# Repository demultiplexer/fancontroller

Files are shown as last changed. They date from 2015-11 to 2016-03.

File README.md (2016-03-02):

# Open source programmable fan controller

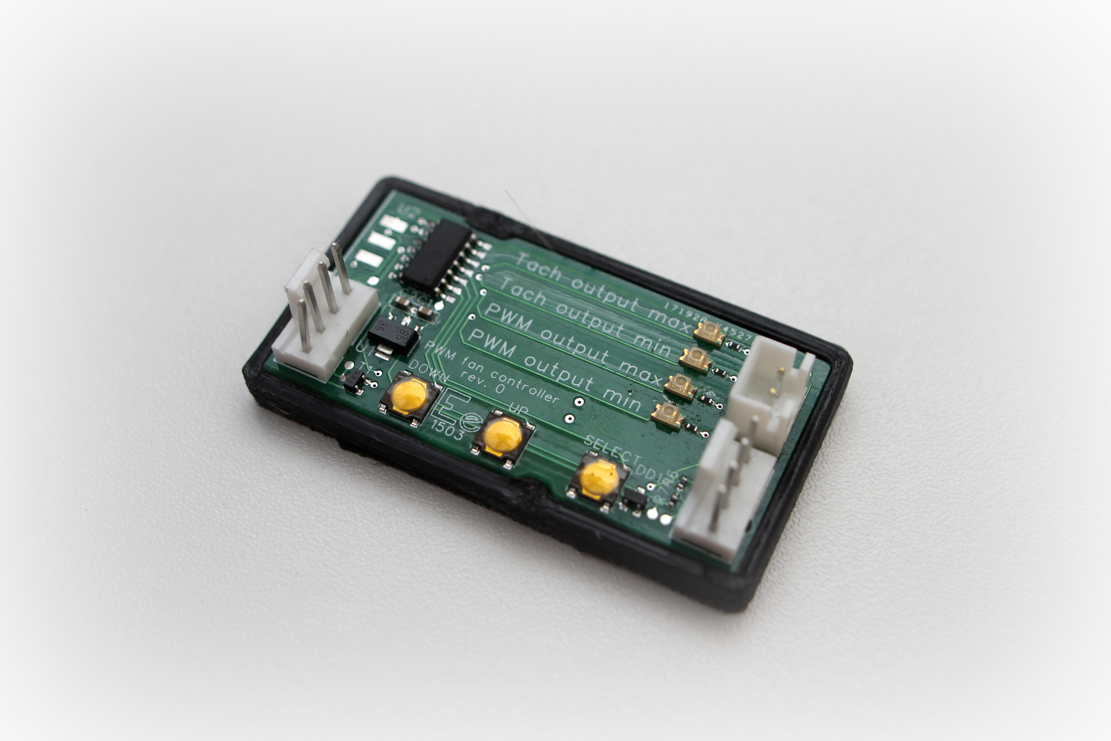
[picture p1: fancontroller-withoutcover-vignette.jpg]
Fan controller PCB and bottom printed enclosure shell (top shell removed)


This is an open source (commons) hardware project to create a fully programmable computer fan controller. The function of this board is to allow the user to both modify the PWM signal from the motherboard ("how fast the motherboard tells the fan to go") as well as the tachometer signal from the fan ("how fast the fan says it's spinning").

One application of this device is in server equipment that require fans to be present and spinning at a certain speed. These fans are often noisy and it helps to replace them with slower-spinning, quieter alternatives. However, motherboard firmware often rejects these fans. With this fan controller, the fan can pretend it's rotating faster than it really is.

This fan controller is completely open hardware and I highly encourage forking. Attribution is not required but I would really like it if you do mention me. I sell these boards including enclosure and wiring on my Tindie shop: https://www.tindie.com/stores/mux/

# Usage

The 4-pin fan connector on the left (marked "INPUT") should be connected to the motherboard using a straight 4-pin jumper cable. The 4-pin fan connector on the right should be connected to the fan. By default, the board does not interfere in the signals between motherboard and fan; it will just relay them as if it does not exist. 

By pressing the 'SELECT' (rightmost) button, you can cycle through the 4 settings: Tach min/max and PWM min/max. The corresponding LED will light up.

By pressing "UP" or "DOWN", the selected setting will be modified positively and negatively, respectively. 

Increasing or decreasing the "Tach output min" increases and decreases the minimum RPM signal that the board will send to the motherboard in steps of 500 rpm (steps of 1000 rpm above 5000 rpm). This way, the motherboard will 'think' the fan turns quicker than it actually does. The "Tach output max" signal works the same, but with respect to the upper limit of RPM.

Modifying the "PWM output min" and "PWM output max" settings changes how the fan responds to motherboard PWM signals. For instance, if both these settings are at 0, the fan controller will always output 0% PWM irrespective of the motherboard signal. Similarly, if the 'min' setting is at 50% and the 'max' setting is at 100%, the fan controller will instruct the fan to rotate at 50% even when the motherboard says it should rotate slower.

# How to build this

First of all, you can [buy it from me](https://www.tindie.com/stores/mux/). Barring that, you will need:

 - The PCB. You can order this at many PCB manufacturers like Itead studio, Seeed studio, Elecrow, PCBCART, Ledsee, Olimex, Eurocircuits. I have conveniently included a .zip file with all the gerber files in the required format for most manufacturers. Just go to their PCB prototyping service and upload [this file](/Gerber files/Orderable file format/fancontroller.zip).
 - The parts. I order my parts at nl.farnell.com, the Dutch branch of Element 14. The part list uses Farnell part numbers. If you have a Farnell account, go to your shopping cart and go to the link 'Quick Paste'. Then paste the text inside [this file](/schematics and PCB layout/BOM-element14.txt) into the entry box and you are done.
 - The enclosure. This can be printed using the .stl files provided in [this folder](/enclosure/). This folder also has some examples of how the enclosure should look in your 3D printing software. *PLEASE READ THE INSTRUCTIONS IN 'enclosure/instructions.txt'*
 - A straight 4-pin fan cable. You can either make this yourself using [this connector housing](http://nl.farnell.com/wurth-elektronik/61900411621/housing-2-54mm-4way/dp/1841379), [these contacts](http://nl.farnell.com/wurth-elektronik/61900113722dec/contact-2-54mm-crimp-awg28-22/dp/1841425), some wire and suitable crimpling pliers, or you can try to find ready-made cables on e.g. eBay. I do not currently have any recommendations for ready-made cables.
 - An AVRISP mkII or other AVR programmer witht 6-pin programming header
 - Either Atmel Studio 6.2+ or avrdude. The project is Atmel Studio-based, but you can just flash [the .hex file](/firmware-v2/fancontroller-v2/fancontroller-v2/Debug)
 
 The PCB uses pretty coarse parts, it should be solderable by anybody with a smattering of soldering experience. Don't be afraid of the SOT-323 parts on the board, nor the 0402 resistors; anybody can solder those if you just try :) For the best soldering results, I highly recommend using solder paste and oven reflow. The buttons ARE reflow compatible. I recommend the website [smtstencil.co.uk](http://smtstencil.co.uk/) for all your stencil needs. The gerber files for standard stencils are inside the gerber folder.
 
 After you produced the board and enclosure, you need to program it. The board has a side-mounted footprint for a standard AVRISP mkII programming header, with pin 1 on the REVERSE SIDE of the board. The enclosure does not support this header, so after you are done programming you need to desolder it to fit it into the enclosure.
 
 # Firmware hacking
 
I highly recommend watching the in-depth technical explanation videos on my Youtube channel: https://youtube.com/PowerElectronicsBlog

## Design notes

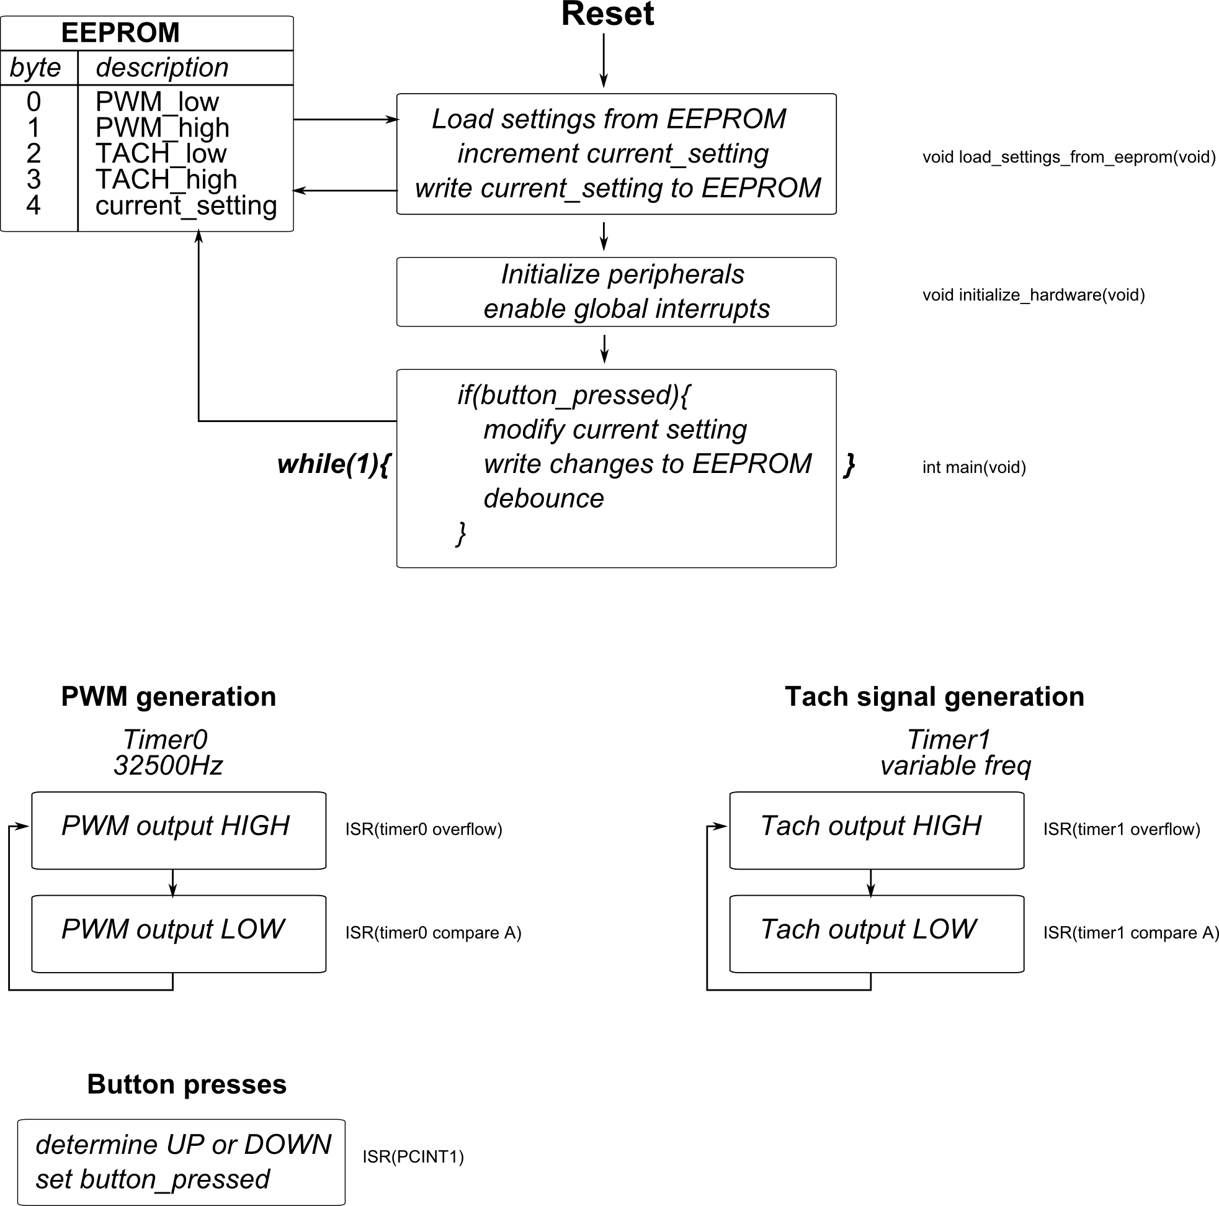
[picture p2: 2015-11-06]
firmware-flowchart-overview.png

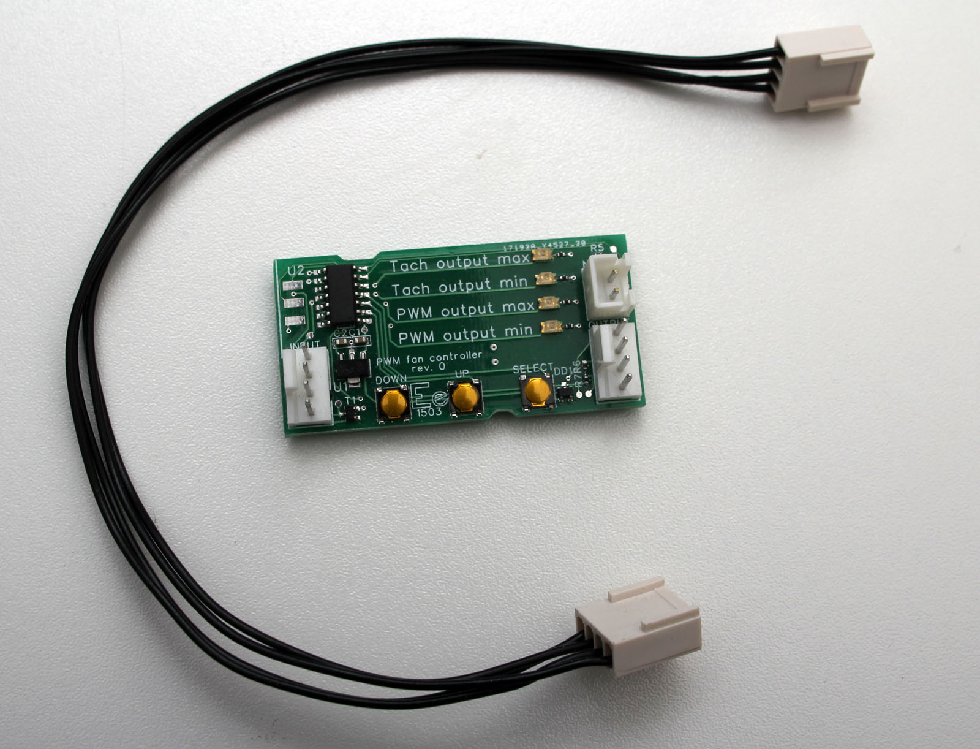
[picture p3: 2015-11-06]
overview-set.jpg

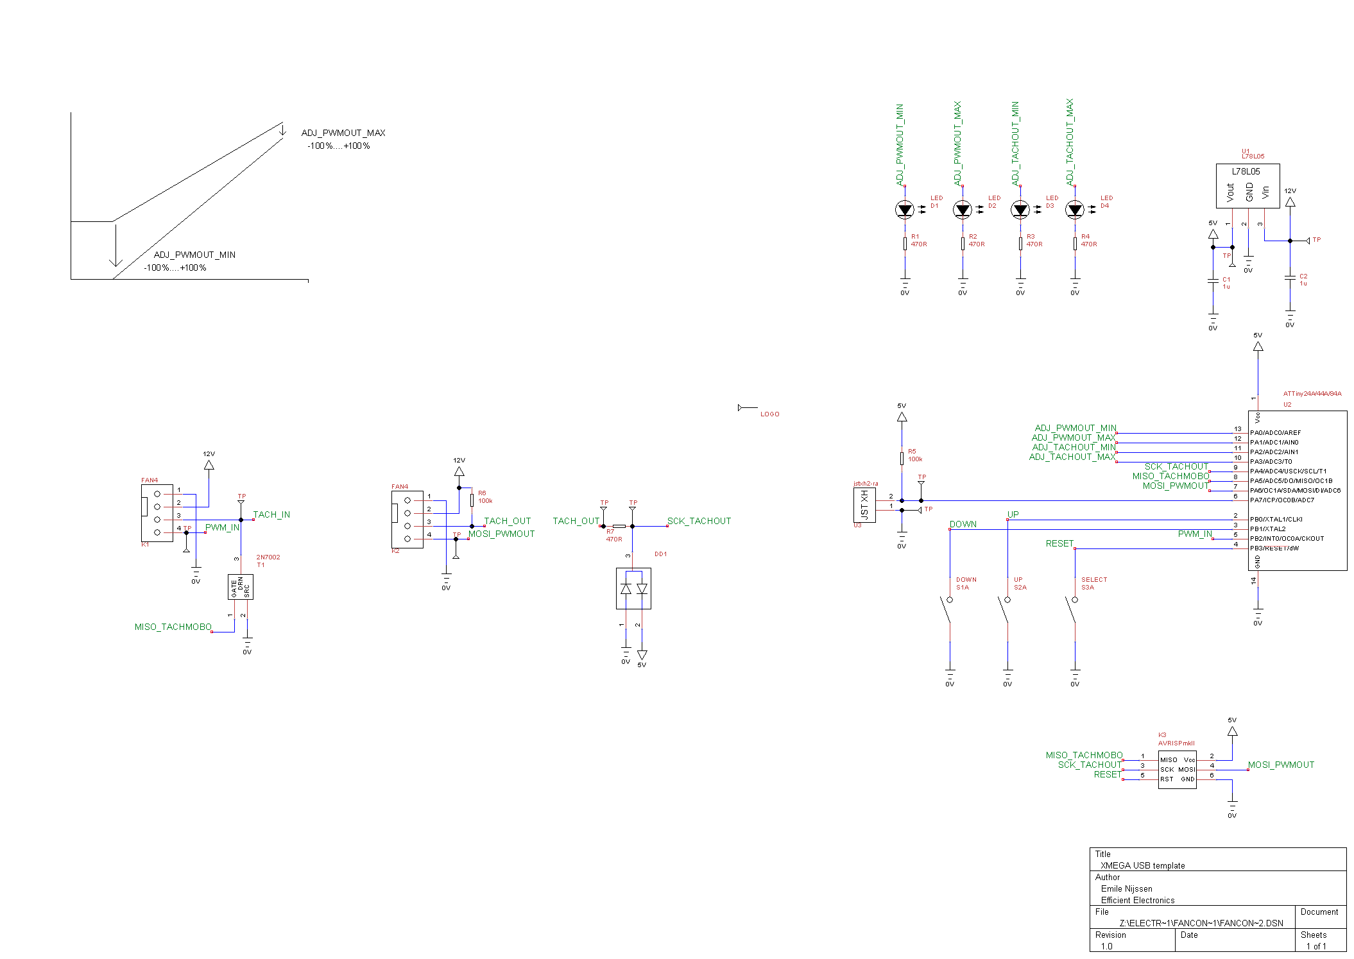
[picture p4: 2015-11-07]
schematics and PCB layout/fancontroller-rev1 schematic.png

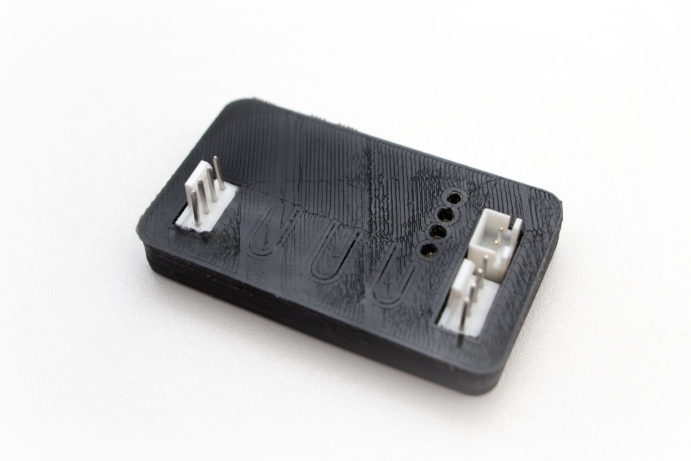
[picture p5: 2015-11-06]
fancontroller-withcover-vignette.jpg

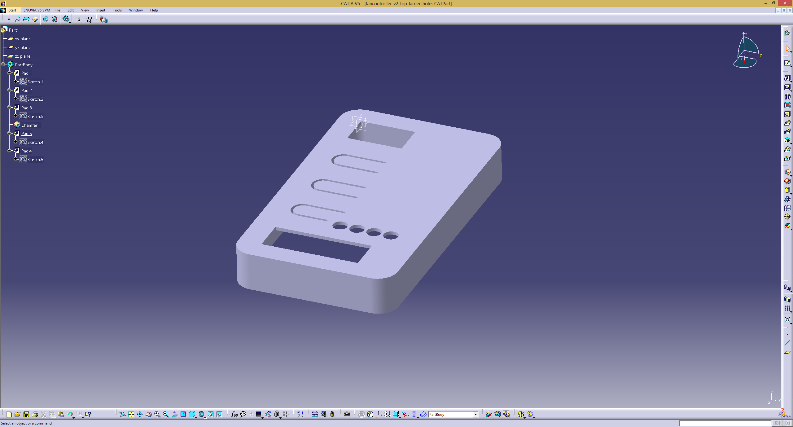
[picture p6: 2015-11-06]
enclosure-top-image.png

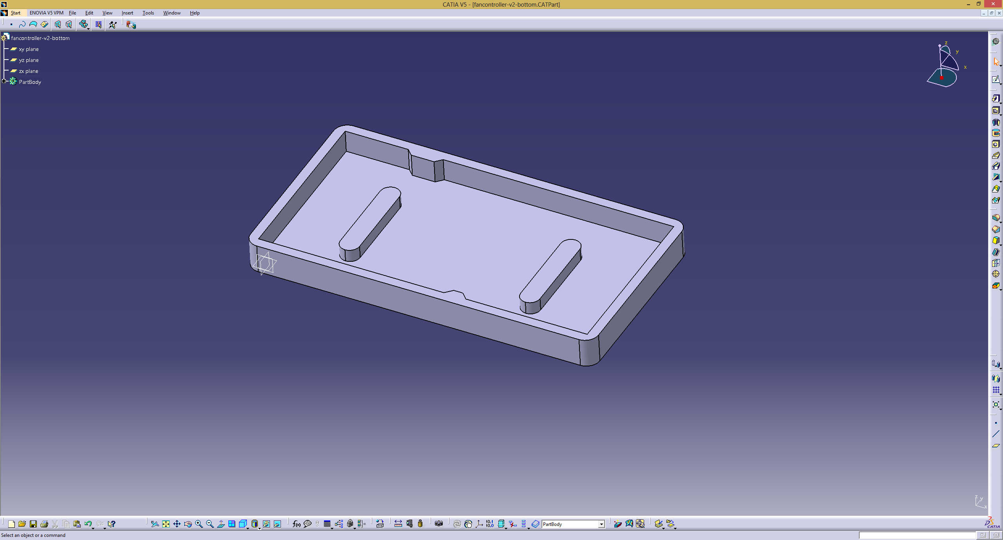
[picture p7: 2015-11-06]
enclosure-bottom-image.png

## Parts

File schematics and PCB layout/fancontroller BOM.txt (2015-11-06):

This document is a direct export from TinyCAD. For a Farnell/element14 Quick Paste-compatible list, refer to BOM-element14.txt

====+  Parts List for Z:\ELECTR~1\FANCON~1\FANCON~1.DSN  +====

T1                            1   2N7002,2N7002 N-mosfet,SOT-323,1894711
U2                            1   ATTiny24A/44A/84A,8-bit MCU,SOP-14,2425140
K3                            1   AVRISPmkII,AVRISP mkII ISP header,3x2HDR-edgemount,3418492
DD1                           1   BAT54S,Dual schottky diode,SOT-323,1081212
C1,C2                         2   C,Capacitor,C0603R,1759039,1u
S1                            1   DOWN,DPST switch,smallswitch-smd,2103642
K1,K2                         2   FAN4,4-pin fan connector,4-pin fan connector,2313705
LOGO                          1   JI,Connection Input,efficientelectronics_small,NO FARNELL
U1                            1   L78L05,STMicroelectronics L78L05 LDO 5V,SOT-89,2112604
D1,D2,D3,D4                   4   LED,Light-Emitting Diode,LED0603R,2426228,,..,..,..,..,..,..,..,..,..,..
R5,R6                         2   RESISTOR,Resistor,R0402R,2072519,100k
R1,R2,R3,R4,R7                5   RESISTOR,Resistor,R0402R,2447178,470R
S3                            1   SELECT,DPST switch,smallswitch-smd,2103642
J1,J2,J3,J4,J5,J6,J7,J8,
J9                            9   TP,Connection Input,test_dot,NO FARNELL
S2                            1   UP,DPST switch,smallswitch-smd,2103642
U3                            1   jstxh2-ra,JST XH 2-way connector (right angle),jstxh2,1516276

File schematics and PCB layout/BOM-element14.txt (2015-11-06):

2112604,1
2313705,10
1081212,5
1759039,10
2072519,100
3418492,1
2425140,1
1894711,1
2426228,4
2103642,3
1516276,10
2447178,10

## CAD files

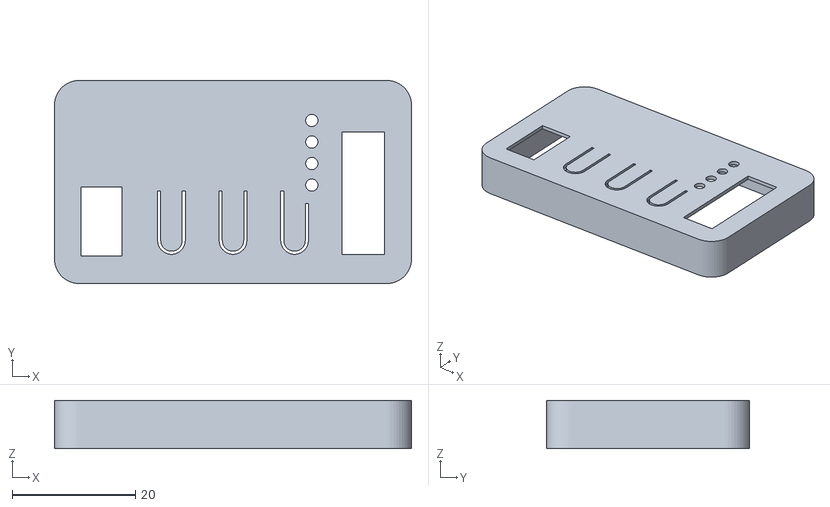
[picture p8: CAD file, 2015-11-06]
enclosure/fancontroller-v2-top.stl
58.0 x 33.0 x 7.80

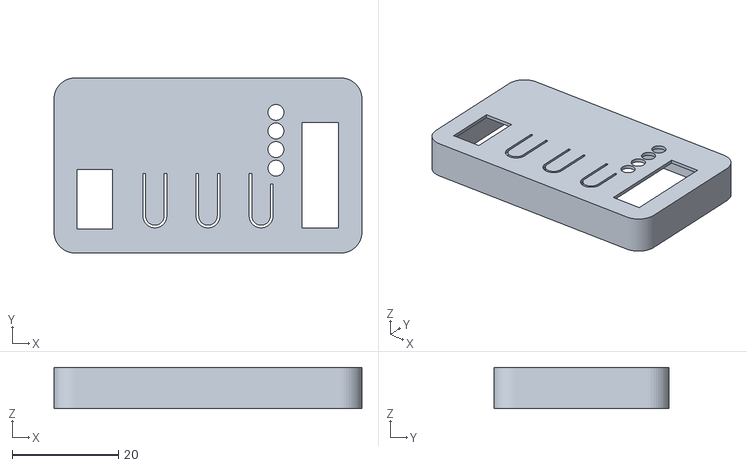
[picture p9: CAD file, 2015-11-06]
enclosure/fancontroller-v2-top-larger-holes.stl
58.0 x 33.0 x 7.80

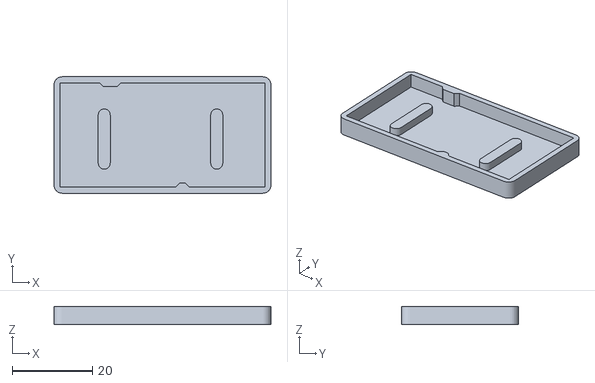
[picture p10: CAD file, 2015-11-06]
enclosure/fancontroller-v2-bottom.stl
54.0 x 29.0 x 4.60

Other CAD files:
enclosure/fancontroller-v2-bottom.CATPart
enclosure/fancontroller-v2-top-larger-holes.CATPart
enclosure/fancontroller-v2-top.CATPart

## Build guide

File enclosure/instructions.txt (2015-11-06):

This enclosure is created using CATIA v5r14. It cannot be modified or imported using any open source software. Sorry for that, but this is my workflow. I included 3D printable files (.stl metric).

The enclosure is designed to be 3D printed using any 3-axis 3D printer, and then snapped together. The PCB and enclosure have alignment notches. Tolerance between the parts is 0.5mm, which should yield a good snap-action and a snug fit.

Printing notes:
- The upper shell is 0.7mm thick, which is too thin for some 3D printing services using certain plastics
- The upper shell has bend-action buttons built in. Make sure you do not overextrude, as this will weld the buttons to the rest of the shell and render them useless
- The upper shell has small (1mm) holes to let the LEDs shine through. Some 3D printing slicers and printers use too few line segments on small circular features and will render these holes closed. A version with larger holes is included (fancontroller-v2-top-larger-holes). Do not print this if the small-hole version works well; you may risk breakages because the material between the holes gets really thin.
- The upper shell has a 0.7mm thick face, so it is advised to use 0.1 or 0.15mm layer thickness. The default 0.35mm on many slicers may be a bit coarse and lead to ugly faces.
- I have included pictures of the 3D model and the first prototype print (which, admittedly, isn't very pretty) to show how your printing result should look.

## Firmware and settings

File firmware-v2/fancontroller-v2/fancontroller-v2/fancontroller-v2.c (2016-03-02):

/*
 * fancontroller_v2.c
 *
 * Created: 25/07/2015 14:23:02
 *  Author: Emile Nijssen aka mux aka demultiplexer
 *
 * This is an almost-completely interrupt driven programmable fan controller firmware
 * the firmware is kind of complicated as a result of kind of underpowered hardware 
 * (to reduce cost and make the board easier to solder for beginners/casual hackers)
 * I highly recommend taking note of the documentation provided if you wish to modify
 * the firmware. 
 *
 * This is fully open source, i.e. I release this into commons. Do with this as you like
 * Attribution is not required but still encouraged
 *
 *
 * If you like this project, I sell these boards as well as other projects in my Tindie store:
 * https://www.tindie.com/stores/mux/
 *
 * I do provide support on this project via github, but I tend to be busy and kind of slow to respond
 * So in practice you are probably on your own for complicated bugs or feature requests
 *
 
 
 /*
 General firmware layout
 
 This board allows the user to clip the PWM and RPM signals of a fan/motherboard to some lower
 or higher value. 
 
 Given that timer1 is connected to MOSI_PWMOUT and that interrupt needs to be automated,
 we use this to create 25kHz PWM. That leaves us with timer2 for generating MISO_TACHMOBO.
 
 Unfortunately, after lots of testing, it seems that actually MISO_TACHMOBO is most important
 to get 100% right, so we're going to sporadically use timer1 for measuring other stuff.
 
 Essentially:
 - Timer1 always outputs the PWM duty cycle to OC1A
 - Timer1, on overflow, triggers an interrupt that increments the value tach
 - when tach reaches tach_period, MISO_TACHMOBO is XORed and lasttach is incremented
 - Timer0 just freeruns
 - whenever an RPM pulse from the fan is detected, we check if lasttach is exactly 1
 - if lasttach is less than 1, we output too few tachometer pulses to the motherboard so we speed up
 - likewise if lasttach is more than 1, we are outputting too many tach pulses and we need to slow down
 - the main loop services button presses
 - the main loop also measures the PWM duty cycle using timer0
 
 The user can set minima and maxima for the PWM duty cycle and reported RPM using the buttons
 - Adjusting "tach output max" clips the max. RPM reported from the fan to the motherboard in 500rpm decrements 
 - Adjusting "tach output min" clips the min. RPM reported from the fan to the motherboard in 500rpm increments 
 - Adjusting "pwm output max" clips the max. PWM sent to the fan to the motherboard in 5% decrements 
 - Adjusting "pwm output min" clips the max. RPM sent to the fan to the motherboard in 5% increments
 
 */ 

#include "fancontroller-v2.h"						//contains macros and named numbers
#include <avr/io.h>									//required to do anything
#include <avr/interrupt.h>							//interrupt handling
#include <avr/eeprom.h>								//eeprom reading/writing
#include <util/delay.h>								//delay handling

//tach/pwm period variables
volatile	uint16_t	tach_period			= 0;	//variable that stores the computed output tach signal to be sent to MISO_TACHMOBO
volatile	uint16_t	tach				= 0;	//running variable generating the tach signal
volatile	uint16_t	lasttach			= 0;	//running variable used to compare to tach 
volatile	uint16_t	pwm_duty_m			= 0;	//variable that stores the measured number of cpu cycles between an up- and downslope on the PWM signal

//The settings are stored in EEPROM as a value 0-20 that can be manipulated with the buttons,
//but the actual meaning of those values is determined by:
//  PWM settings: phys_setting[3:4] = eeprom_settings[3:4] * 2
//	Tach settings: phys_setting[0:1] = tach_lut[eeprom_settings[3:4]]

volatile	uint8_t		eeprom_settings[4]	= {0,20,10,10};
volatile	uint16_t	phys_settings[4]	= {750,27,20,20};
volatile	uint8_t		CURRENT_SETTING		= 0;	//contains the setting currently being manipulated

//												1     2     3     4     5     6     7     8    9    10   11   12   13   14   15    16    17    18    19   20
//											   500   1000  1500  2000  2500  3000  3500  4000 4500 5000 6000 7000 8000 9000 10000 11000 12000 13000 14000 15000
			uint16_t	tach_lut[20]		= {750,  375,  250,  188,  150,  125,  107,  94,  83,  75,  63,  54,  47,  42,  38,   34,   31,   29,   27,   25};
	
//button variables
volatile uint8_t		button_pressed		= 0;	//boolean telling the main loop whether a button was pressed

		uint8_t			i					= 0;	//iteration variable
		uint8_t			temp				= 0;

int main(void)
{
	load_settings_from_eeprom();
	initialize_hardware();
   
    while(1)
    {
		//a button was pressed
        if(button_pressed){	
			if(button_pressed == 1){	//up
				if(eeprom_settings[CURRENT_SETTING] < 19) eeprom_settings[CURRENT_SETTING]++;
			} else {					//down
				if(eeprom_settings[CURRENT_SETTING] > 0) eeprom_settings[CURRENT_SETTING]--;
			}
			
			
			//and modify the corresponding phys_setting
			if(CURRENT_SETTING < 2){
				phys_settings[CURRENT_SETTING] = tach_lut[eeprom_settings[CURRENT_SETTING]];
			} else {
				phys_settings[CURRENT_SETTING] = eeprom_settings[CURRENT_SETTING] * 2;
			}
			
			button_pressed = 0;	//release flag so we can service another button press
		}
		
		//when we're not servicing button presses, we're measuring the PWM signal. 
		//this is a very fast signal, so we don't want to use interrupts for this
		//hence we're doing this in the main loop so we can be easily interrupted by more
		//important stuff.
		
		//wait for a leading edge
		temp = 50;
		while(!(PINB & PWM_IN_PIN) && temp){temp++;}	//we include a counter to allow this loop to exit after a short timeout
		temp = 50;	//reset temp
		TCNT0 = 0;	//start the timer
		while(PINB & PWM_IN_PIN && temp){temp++;}
		pwm_duty_m = TCNT0;
			
		//at this time we either have some TCNT value between 0-40(ish) representing the duty cycle of the PWM signal
		//or we have a value of temp=0 because we had a timeout
		if(temp){	//non-timeout
			if(pwm_duty_m < phys_settings[3] && pwm_duty_m > phys_settings[2]){
				OCR1A = pwm_duty_m;				
			}
		}
    }
}

/****************************/
/* INITIALIZATION FUNCTIONS */
/****************************/

void load_settings_from_eeprom(void){
	//load the individual settings from EEPROM
	for(i = 0; i < 4; i++){
		eeprom_settings[i]	= eeprom_read_byte((uint8_t *) i); if(eeprom_settings[i] > 19){ eeprom_settings[i] = 10; }
	}
	
	CURRENT_SETTING		= eeprom_read_byte((uint8_t *) 4); 
	
	//increment current setting, check if it isn't exceeding our settings pages and re-store the incremented value to EEPROM
	CURRENT_SETTING++; if(CURRENT_SETTING > MAX_SETTING) CURRENT_SETTING = 0;
	eeprom_write_byte((uint8_t *) 4, CURRENT_SETTING);
	
	//translate the offset settings into actual usable numbers for our calculations
	phys_settings[0] = tach_lut[eeprom_settings[0]];
	phys_settings[1] = tach_lut[eeprom_settings[1]];
	phys_settings[2] = eeprom_settings[2] * 2;
	phys_settings[3] = eeprom_settings[3] * 2;
	
	//turn on the relevant LED
	PORTA |= (1 << CURRENT_SETTING);
}

void initialize_hardware(void){
	//set port direction bits to 1 for all output pins
	DDRA	= ADJ_PWMOUT_MIN_PIN | ADJ_PWMOUT_MAX_PIN | ADJ_TACHOUT_MIN_PIN | ADJ_TACHOUT_MAX_PIN |
			  MISO_TACHMOBO_PIN | MOSI_PWMOUT_PIN;
	DDRB	= 0;
	
	//pull-up on SCK_TACHMOBO, UP_PIN and DOWN_PIN
	PORTA  |= MISO_TACHMOBO_PIN;
	PORTB  |= UP_PIN | DOWN_PIN;
	
	//initialize PCINT0
	//PCINT0 triggers on SCK_TACHOUT, measuring the tachometer signal produced by the attached fan
	//it always triggers on the positive edge
	PCMSK0 |= (1 << PCINT4);
	
	//initialize PCINT1
	//PCINT1 triggers on any state change of the UP and DOWN buttons
	PCMSK1 |= (1 << PCINT8) | (1 << PCINT9);
	GIMSK  |= (1 << PCIE1) | (1 << PCIE0);
	
	//initialize TCNT0
	//Timer/counter0 is used for measurements only, and simply freeruns
	TCCR0B	= TIMER_CLKSEL_DIV8;
		
	//initialize TCNT1
	//Timer/counter1 is a 16-bit counter that just counts at clkio/2
	//It overflows at 160 to generate a 25kHz waveform
	//and it outputs to PA6 (OC1A) to physically output that PWM waveform
	//The overflow interrupt is used to generate the MISO_TACHMOBO signal on PA5
	TCCR1A	= (1 << COM1A1) | (1 << WGM11);													//enable output to OCR1A
	TCCR1B	= TIMER_CLKSEL_DIV8 | (1 << WGM13) | (1 << WGM12);								//run at clkio/64, use WGM3:0=1110, i.e. fast PWM with TOP=ICR1 and both COMPA and COMPB intact
	TIMSK1	= TIMER_ENABLE_OVF_INTERRUPT;													//enable overflow interrupt
	OCR1A	= 20;																			//duty is 50% by default
	ICR1	= 40;																			//period is 160, equivalent to 25kHz.
	
	sei();																					//enable global interrupts
}

/**********************/
/* INTERRUPT HANDLERS */
/**********************/

//timer1 overflow interrupt, set MISO_TACHMOBO
//timer1 overflow also acts as an arbiter for the measurement cycle
ISR(TIM1_OVF_vect){
	tach++;
	if(tach > tach_period){
		PORTA ^= MISO_TACHMOBO_PIN;
		tach = 0;	
		lasttach++;
	}	
}

//PCINT0 is armed on SCK_TACHOUT
//when PCINT0 is triggered, the fan has completed half a revolution
//ideally, in that time we also want to have output exactly 1 pulse, except
//when we're at the setting limits. So if we actually output more than one
//pulse we should slow down, and conversely.
ISR(PCINT0_vect){
	if(!lasttach){	//we're outputting too slow a signal, speed up!
		if(tach_period > phys_settings[0]){ tach_period--; }
	}
	
	if(lasttach > 1){
		if(tach_period < phys_settings[1]){ tach_period++; }
	}
	
	lasttach = 0;
}

//PCINT1 is armed on UP and DOWN
//a button press is going to cause either UP or DOWN to change to LOW, so we test for that to ascertain
//whether we need to increment or decrement the current value
ISR(PCINT1_vect){
	if(!button_pressed){	//wait until main() cleared the previous interrupt	
		if(!(PINB & UP_PIN)){
			button_pressed = 1;	//UP
		} 
		if(!(PINB & DOWN_PIN)){
			button_pressed = 2; //DOWN
		}
	}
	
	//the rest is done in main() so as not to choke out other interrupts
}

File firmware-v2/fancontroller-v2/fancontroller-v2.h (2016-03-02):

/* Macros */
#define		TIMER_CLKSEL_DIV1				(1 << CS10)
#define		TIMER_ENABLE_OVF_INTERRUPT		(1 << TOIE1)
#define		TIMER_ENABLE_COMPA_INTERRUPT	(1 << OCIE0A)

/* pins */
//PORTA
#define		ADJ_PWMOUT_MIN_PIN	(1 << 0)
#define		ADJ_PWMOUT_MAX_PIN	(1 << 1)
#define		ADJ_TACHOUT_MIN_PIN	(1 << 2)
#define		ADJ_TACHOUT_MAX_PIN	(1 << 3)
#define		SCK_TACHOUT_PIN		(1 << 4)
#define		MISO_TACHMOBO_PIN	(1 << 5)
#define		MOSI_PWMOUT_PIN		(1 << 6)
#define		NTC_PIN				(1 << 7)

#define		ALL_LED_MASK		0b00001111

//PORTB
#define		UP_PIN				(1 << 1)	//ERRATUM: Up&Down on schematic wrong way around compared to layout, so we're fixing this in firmware
#define		DOWN_PIN			(1 << 0)	//ERRATUM: Up&Down on schematic wrong way around compared to layout, so we're fixing this in firmware
#define		PWM_IN_PIN			(1 << 2)
#define		SELECT_PIN			(1 << 3)

/* Function prototypes */
void initialize_hardware(void);

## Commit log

2015-11-06 Initial commit of firmware, schematics, PCB and docs
    [fancontroller - rev1.dsn, fancontroller-v2-bottom.CATPart, fancontroller-v2-bottom.stl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]
2015-11-06 Illustrations and BOM added
2015-11-07 schematic image
